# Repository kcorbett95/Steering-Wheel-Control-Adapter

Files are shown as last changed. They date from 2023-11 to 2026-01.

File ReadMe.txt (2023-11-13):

This project is meant to adapt steering wheel media control buttons to aftermarket stereo head-units. It requires the head-unit to use an analog remote
input, usually in the form of a 3.5mm headphone jack in the back of the unit, and the vehicle steering wheel buttons to be a resistor-network type where
each button corresponds to a different resistance value between two wires. Vehicles with many buttons often have 2 input wires and a 3rd reference wire,
where the resistances can be between the reference wire and either input wire, doubling the number of input buttons for the same resistances.

The existing code is currently working on a 2015 Subaru Crosstrek/Impreza and a Pioneer AVH4500NEX head unit. You will need to consult the vehicle
factory service manual to determine what the resistance values for each steering wheel button is, or do some testing with a multimeter to measure each
button manually (this takes forever, don't do this unless you have no other option.) You will also need to know the remote input values the head unit
needs for each function. This information is kindof difficult to find, but I found the values for Pioneer head units after a few hours of digging through
forums and such. An email to the support of your head-unit manufacturer might be helpful in finding this information.

************   MAPPING FUNCITONS    **************
Once you have the required resistance values for both your vehicle, and the corresponding head unit values, the mapping procedure is fairly easy:

1) In the beginning of the SWC_adapter.ino arduino file, you will find the definitions for the head unit values. You will need to replace these values
with the ones for your head unit. 

For example, if your volume up function needs a 55kOhm input, replace the value: 

#define volUp 55000

Repeat this process for the rest of the defined functions. If your vehicle does not have a button corresponding to one of these values, you can either
replace the value with "noBtn" without the quotes if you do not wish to use this function, or you can make a custom value for a button-hold to implement
a different function in later steps (more advanced).

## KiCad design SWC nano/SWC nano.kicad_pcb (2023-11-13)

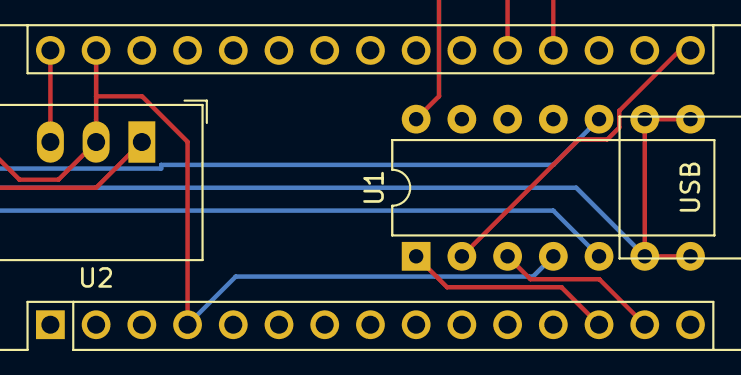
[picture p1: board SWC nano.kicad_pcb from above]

Board: 2 copper layers, 3 parts (0 on the bottom side), 6 nets.

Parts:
A1: Arduino_Nano_v3.x; Arduino_Nano
U1: MCP4251-xxxx-P; DIP-14_W7.62mm
U2: R-785.0-0.5; Converter_DCDC_RECOM_R-78E-0.5_THT

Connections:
/Remote_Ref: U1.6 (P1W), U1.7 (P1A), U1.8 (P0A), U1.9 (P0W)
/SW_Pos_2: A1.27 (+5V), A1.30 (VIN), U1.14 (VDD), U2.3 (OUT)
GND: A1.4 (GND), A1.29 (GND), U1.4 (VSS), U2.2 (GND)
unnamed: A1.13 (D10), U1.1 (~CS)
unnamed: A1.14 (D11), U1.3 (SDI)
unnamed: A1.16 (D13), U1.2 (SCK)

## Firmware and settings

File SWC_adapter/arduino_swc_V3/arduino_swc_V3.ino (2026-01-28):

#include <AceButton.h>
using namespace ace_button;

// Set the SWC input PINs
static const uint8_t BUTTON_PIN1 = A0;
static const uint8_t BUTTON_PIN2 = A1;

// NEC output pin that drives the transistor base
static const uint8_t NEC_PIN = 13;

// Kenwood NEC parameters
static const uint8_t NEC_ADDRESS = 0xB9;
static const uint16_t NEC_BASE = 562;         // us
static const uint16_t NEC_HDR_MARK = 9000;    // 16 * 562.5
static const uint16_t NEC_HDR_SPACE = 4500;   // 8 * 562.5
static const uint16_t NEC_BIT_MARK = 562;
static const uint16_t NEC_ONE_SPACE = 1687;   // 3 * 562.5
static const uint16_t NEC_ZERO_SPACE = 562;
static const uint16_t NEC_RPT_SPACE = 2250;   // 4 * 562.5
static const uint16_t NEC_REPEAT_INTERVAL_MS = 95;

// Event bookkeeping for NEC repeat frames
static uint8_t lastCommand = 0xFF;
static bool repeatActive = false;
static uint32_t lastRepeatMillis = 0;

// Create AceButton objects, with their virtual pin number.
// Each virtual PIN relates to a resistance value on the ladder
static const uint8_t NUM_BUTTONS_1 = 6;
static AceButton volUp((uint8_t)0);
static AceButton volDn(1);
static AceButton trackUp(2);
static AceButton trackDn(3);
static AceButton listInfo(4);
static AceButton back(5);
//static AceButton open1(11);
static AceButton* const BUTTONS_1[NUM_BUTTONS_1] = {
  &volUp,     // 0
  &volDn,     // 48
  &trackUp,   // 111
  &trackDn,   // 197
  &listInfo,  // 319
  &back,      // 530
  //&open1,     // 1023
};

// Virtual pins 6-10 map low->high thresholds: onHook, offHook, source, voice, mute
static const uint8_t NUM_BUTTONS_2 = 5;
static AceButton muteEnter((uint8_t)0);
static AceButton voice(1);
static AceButton source(2);
static AceButton offHook(3);
static AceButton onHook(4);
//static AceButton open2(12);
static AceButton* const BUTTONS_2[NUM_BUTTONS_2] = {
  &muteEnter, // 0
  &voice,     // 47
  &source,    // 108
  &offHook,   // 195
  &onHook,    // 317
  //&open2,     // 1023
};

// Map virtual button index -> Kenwood NEC command (LSB first). Update as needed.
// Unused entries should be 0xFF.
//0xFC,   //AM tuner
//0x83,   //power off

static const uint8_t NEC_COMMANDS_1[NUM_BUTTONS_1] = {
  0x14,  // vol+
  0x15,  // vol-
  0x0B,  // track +
  0x0A,  // track -
  0x8A,  // list/info -> phone menu
  0x0E,  // back (play/pause)
};

static const uint8_t NEC_COMMANDS_2[NUM_BUTTONS_2] = {
  0x16,  // mute/enter
  0x8B,  // voice
  0x13,  // source
  0x88,  // off-hook
  0x89,  // on-hook
};
static const uint8_t NEC_CMD_PLAY_PAUSE = 0x0E;

//
// Define the ADC voltage levels for input pin 1 buttons (ascending, one per button),
// plus the open (no-button) level as the last entry.
static const uint8_t NUM_LEVELS_1 = NUM_BUTTONS_1 + 1;
static const uint16_t LEVELS_1[NUM_LEVELS_1] = {
  0     /* VOL+ */,
  47   /* VOL- */,
  111   /* Track + */,
  196   /* Track - */,
  319   /* List/Info */,
  529  /* Return/back */,
  1023  /* Open */,
};

// Define the ADC voltage levels for input pin 2 buttons (ascending, one per button),
// plus the open (no-button) level as the last entry.
static const uint8_t NUM_LEVELS_2 = NUM_BUTTONS_2 + 1;
static const uint16_t LEVELS_2[NUM_LEVELS_2] = {
  0     /* Mute/Enter */,
  48   /* Voice */,
  111   /* SOURCE */,
  195   /* Off-Hook */,
  319  /* On-Hook */,
  1023  /* Open */,
};

// The LadderButtonConfig constructor binds the AceButton to the
// LadderButtonConfig.
static LadderButtonConfig buttonConfig(
  BUTTON_PIN1, NUM_LEVELS_1, LEVELS_1, NUM_BUTTONS_1, BUTTONS_1, 1);

static LadderButtonConfig buttonConfig_2(
  BUTTON_PIN2, NUM_LEVELS_2, LEVELS_2, NUM_BUTTONS_2, BUTTONS_2, 1);

void handleEventA0(AceButton*, uint8_t, uint8_t);
void handleEventA1(AceButton*, uint8_t, uint8_t);
void handleEventWithMap(AceButton*, uint8_t, const uint8_t*, uint8_t, const __FlashStringHelper*, bool);
void sendKenwood(uint8_t cmd);
void sendKenwoodRepeat();
void handleSerialCommand();
void necMark(uint16_t usec);
void necSpace(uint16_t usec);
void necSendByte(uint8_t data);
void necSendFrame(uint8_t addr, uint8_t cmd);

void setup() {
  delay(1000);  // some microcontrollers reboot twice
  Serial.begin(115200);
  // Wait briefly for Serial on native-USB boards; don't block forever in vehicle power.
  unsigned long serialStart = millis();
  while (!Serial && (millis() - serialStart < 2000)) {
  }
  Serial.println(F("setup(): begin"));

  // Don't use internal pull-up resistor
  pinMode(BUTTON_PIN1, INPUT);
  pinMode(BUTTON_PIN2, INPUT);

  // NEC output defaults low; transistor pulls line when high.
  pinMode(NEC_PIN, OUTPUT);
  digitalWrite(NEC_PIN, LOW);

  // Configure the ButtonConfig with the event handler.
  buttonConfig.setEventHandler(handleEventA0);
  buttonConfig.setFeature(ButtonConfig::kFeatureClick);
  buttonConfig.setFeature(ButtonConfig::kFeatureDoubleClick);
  buttonConfig.setFeature(ButtonConfig::kFeatureLongPress);
  buttonConfig.setFeature(ButtonConfig::kFeatureRepeatPress);
  buttonConfig.setFeature(ButtonConfig::kFeatureSuppressAfterClick);
  buttonConfig.setFeature(ButtonConfig::kFeatureSuppressClickBeforeDoubleClick);
  buttonConfig.setFeature(ButtonConfig::kFeatureSuppressAfterLongPress);

  buttonConfig_2.setEventHandler(handleEventA1);
  buttonConfig_2.setFeature(ButtonConfig::kFeatureClick);
  buttonConfig_2.setFeature(ButtonConfig::kFeatureDoubleClick);
  buttonConfig_2.setFeature(ButtonConfig::kFeatureLongPress);
  buttonConfig_2.setFeature(ButtonConfig::kFeatureRepeatPress);
  buttonConfig_2.setFeature(ButtonConfig::kFeatureSuppressAfterClick);
  buttonConfig_2.setFeature(ButtonConfig::kFeatureSuppressClickBeforeDoubleClick);
  buttonConfig_2.setFeature(ButtonConfig::kFeatureSuppressAfterLongPress);

  
  
  Serial.println(F("setup(): ready"));
}

void loop() {
  // Should be called every 4-5ms or faster, for the default debouncing time
  // of ~20ms.
  buttonConfig.setDebounceDelay(80);
  buttonConfig_2.setDebounceDelay(80);
  buttonConfig.checkButtons();
  buttonConfig_2.checkButtons();
  if (repeatActive && lastCommand != 0xFF) {
    uint32_t now = millis();
    if (now - lastRepeatMillis >= NEC_REPEAT_INTERVAL_MS) {
      sendKenwood(lastCommand);
      lastRepeatMillis = now;
    }
  }
  handleSerialCommand();
}

// The event handler for the button.
void handleEventA0(AceButton* button, uint8_t eventType, uint8_t /* buttonState */) {
  handleEventWithMap(button, eventType, NEC_COMMANDS_1, NUM_BUTTONS_1, F("A0"), true);
}

void handleEventA1(AceButton* button, uint8_t eventType, uint8_t /* buttonState */) {
  handleEventWithMap(button, eventType, NEC_COMMANDS_2, NUM_BUTTONS_2, F("A1"), false);
}

void handleEventWithMap(
    AceButton* button,
    uint8_t eventType,
    const uint8_t* commands,
    uint8_t numButtons,
  const __FlashStringHelper* label,
  bool allowRepeat) {
  uint8_t swButton = button->getPin();
  uint8_t swPress = (eventType);

  if (swButton >= numButtons) {
    return;
  }

  Serial.print(F("handleEvent("));
  Serial.print(label);
  Serial.print(F("): virtualPin: "));
  Serial.print(swButton);
  Serial.print(F("; eventType: "));
  Serial.print(swPress);
  Serial.print(F("; A0: "));
  Serial.print(analogRead(BUTTON_PIN1));
  Serial.print(F("; A1: "));
  Serial.println(analogRead(BUTTON_PIN2));

  uint8_t cmd = commands[swButton];
  if (cmd == 0xFF) {
    return;
  }

  bool isRepeatButton = allowRepeat && (swButton == 0 || swButton == 1);

  switch (swPress) {
    case AceButton::kEventPressed:  // send only on initial press to avoid duplicate click events on release
      lastCommand = cmd;
      repeatActive = false;
      sendKenwood(cmd);
      break;

    case AceButton::kEventLongPressed:
    case AceButton::kEventRepeatPressed:
      if (!allowRepeat && swButton == 0 && swPress == AceButton::kEventLongPressed) {
        lastCommand = NEC_CMD_PLAY_PAUSE;
        repeatActive = false;
        sendKenwood(NEC_CMD_PLAY_PAUSE);
        break;
      }
      if (isRepeatButton) {
        repeatActive = true;
        lastRepeatMillis = 0;
      }
      break;

    case AceButton::kEventReleased:
    case AceButton::kEventLongReleased:
      lastCommand = 0xFF;
      repeatActive = false;
      break;

    default:
      break;
  }
}


void sendKenwood(uint8_t cmd) {
  necSendFrame(NEC_ADDRESS, cmd);
}

void sendKenwoodRepeat() {
  if (lastCommand == 0xFF) {
    return;
  }
  noInterrupts();
  necMark(NEC_HDR_MARK);
  necSpace(NEC_RPT_SPACE);
  necMark(NEC_BIT_MARK);
  interrupts();
}

void handleSerialCommand() {
  if (!Serial.available()) {
    return;
  }

  String line = Serial.readStringUntil('\n');
  line.trim();
  if (line.length() == 0) {
    return;
  }

  char* endptr = nullptr;
  uint8_t cmd = static_cast<uint8_t>(strtoul(line.c_str(), &endptr, 0));
  if (endptr == line.c_str()) {
    Serial.println(F("Invalid command; enter hex or decimal (e.g., 0x14 or 20)"));
    return;
  }

  lastCommand = cmd;
  Serial.print(F("Sending NEC cmd 0x"));
  Serial.println(cmd, HEX);
  sendKenwood(cmd);
}

void necMark(uint16_t usec) {
  digitalWrite(NEC_PIN, HIGH);
  delayMicroseconds(usec);
}

void necSpace(uint16_t usec) {
  digitalWrite(NEC_PIN, LOW);
  delayMicroseconds(usec);
}

void necSendByte(uint8_t data) {
  for (uint8_t i = 0; i < 8; i++) {
    necMark(NEC_BIT_MARK);
    if (data & 0x01) {
      necSpace(NEC_ONE_SPACE);
    } else {
      necSpace(NEC_ZERO_SPACE);
    }
    data >>= 1;
  }
}

void necSendFrame(uint8_t addr, uint8_t cmd) {
  uint8_t naddr = ~addr;
  uint8_t ncmd = ~cmd;

  noInterrupts();
  necMark(NEC_HDR_MARK);
  necSpace(NEC_HDR_SPACE);
  necSendByte(addr);
  necSendByte(naddr);
  necSendByte(cmd);
  necSendByte(ncmd);
  necMark(NEC_BIT_MARK);
  interrupts();
}

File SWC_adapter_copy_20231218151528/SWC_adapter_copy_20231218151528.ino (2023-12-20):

#include <SPI.h>
#define DATAOUT 11//COPI
#define DATAIN  12//CIPO
#define SPICLOCK  13//sck
#define CHIPSELECT 10//cs

//potentiometer selection values, do not alter
#define tip 0b00010001
#define ring 0b00010010
#define Both 0b00010011

//Definitions for output resistances required for stereo, these will need to be changed based on your head-unit and the
//resistance it requires for each media function. See ReadMe for more information
#define noBtn 100000
#define volUp 16000
#define volDn 24000
#define trackUp 8000
#define trackDn 11250
#define listInfo 5750
#define back 62750
#define muteEnter 3500
#define source 1600
#define voice 80000
#define offHook 5000
#define onHook 1500
#define short 0

// initialization code, do not alter
void setup() {
  Serial.begin(9600);
  pinMode(DATAOUT, OUTPUT);
  pinMode(DATAIN, INPUT);
  pinMode(SPICLOCK,OUTPUT);
  pinMode(CHIPSELECT,OUTPUT);
  digitalWrite(CHIPSELECT,HIGH);
  SPI.begin();
  delay(100);
  potWrite(noBtn,Both);
}

//analog read to calculate resistance from vehicle button input, do not alter
double readRes(double analogPin) {
  
  double raw = 0;
  float vout = 0;
  float buffer = 0;
  double res = 0;
  delay(150);
  raw = analogRead(analogPin);
  if (raw>7) {
    buffer = raw * 5;
    vout = buffer / 1024;
    buffer = (5 / vout) - 1;
    res = 1000 * buffer;
    if(res <= 0){
      return noBtn;
    }
    // for debugging, uncomment to view input values in console
    // Serial.print("raw: ");
    // Serial.println(raw);
    // Serial.print("vout: ");
    // Serial.println(vout);
    // Serial.print("Res: ");
    // Serial.println(res);
    delay(50);
    return res;
  }
  else {
    return noBtn;
  }
}

//main function, see ReadMe for information on how to set input ranges and tip/ring output
void loop() {
  
    // Read the values of the two input wires from the steering wheel buttons
    double input1 = readRes(A0);
    double input2 = readRes(A1);

    // Map the values to the corresponding functions
    if (input1 < 25) {
      // Volume Up
      Serial.print("vol up\n");
      potWrite(volUp, tip);
      //delay(5000);
      while(readRes(A0) < 25){
        potWrite(volUp, tip);
        Serial.print("vol up hold\n");
      }
      potWrite(noBtn, tip);
      //delay(5000);
    }

    if (input1 >= 25 && input1 < 75) {
      // Volume Down
      Serial.print("vol dn\n");
      potWrite(volDn, tip);
      //delay(5000);
      while(readRes(A0) >= 25 && readRes(A0) < 75){
        Serial.print("vol dn hold\n");
        potWrite(volDn, tip);
      }
      potWrite(noBtn, tip);
    }

    if (input1 >= 75 && input1 < 175) {
      // Track +
      Serial.print("track up\n");
      potWrite(trackUp, tip);
      while(readRes(A0) >= 75 && readRes(A0) < 175){
        potWrite(trackUp, tip);
        Serial.print("track up hold\n");
      }
      //delay(5000);
      potWrite(noBtn, tip);
    }

    if (input1 >= 175 && input1 < 300) {
      // Track -
      Serial.print("track dn\n");
      potWrite(trackDn, tip);
      while(readRes(A0) >= 175 && readRes(A0) < 300){
        potWrite(trackDn, tip);
        Serial.print("track dn hold\n");
      }
      //delay(5000);
      potWrite(noBtn, tip);
    }

    if (input1 >= 300 && input1 < 575) {
      // List / Song info
      Serial.print("list/info\n");
      potWrite(listInfo, tip);
      while(readRes(A0) >= 300 && readRes(A0) < 575){
        potWrite(listInfo, tip);
        Serial.print("list info hold\n");
      }
      //delay(5000);
      potWrite(noBtn, tip);
    }

    if (input1 >= 575 && input1 < 1200) {
      // Back / Return
      Serial.print("return\n");
      potWrite(back, tip);
      while(readRes(A0) >= 575 && readRes(A0) < 1200){
        potWrite(back, tip);
        Serial.print("return hold\n");
      }
      //delay(5000);
      potWrite(noBtn, tip);
    }

    if (input2 < 25) {
      // Mute/Enter
      Serial.print("mute/enter\n");
      potWrite(muteEnter, tip);
      while(readRes(A1) < 25){
        potWrite(muteEnter, tip);
        Serial.print("mute enter hold\n");
      }
      //delay(5000);
      potWrite(noBtn, tip);
    }

    if (input2 >= 75 && input2 < 175) {
      // Source
      Serial.print("src\n");
      potWrite(source, tip);
      while(readRes(A1) >= 75 && readRes(A1) < 175){
        potWrite(source, tip);
        Serial.print("source hold\n");
      }
      //delay(5000);
      potWrite(noBtn, tip);
    }

    if (input2 >= 25 && input2 < 75) {
      // Voice Control
      Serial.print("voice\n");
      potWrite(short, ring);
      potWrite(voice, tip);
      //delay(2000);  //delay required for some head units to register voice input
      while(readRes(A1) >= 25 && readRes(A1) < 75){
        potWrite(voice, ring);
        Serial.print("voice hold\n");
      }
      potWrite(noBtn, ring);
      potWrite(noBtn, tip);
    }

    if (input2 >= 300 && input2 < 575) {
      // Off-Hook
      Serial.print("off hook\n");
      potWrite(short, ring);
      potWrite(offHook, tip);
      while(readRes(A1) >= 300 && readRes(A1) < 575){
        potWrite(offHook, ring);
        Serial.print("offHook hold\n");
      }
      //delay(5000);
      potWrite(noBtn, tip);
      potWrite(noBtn, ring);
    }

    if (input2 >= 175 && input2 < 300) {
      // On-Hook
      Serial.print("on hook\n");
      potWrite(short, ring);
      potWrite(onHook, tip);
      while(readRes(A1) >= 175 && readRes(A1) < 300){
        potWrite(onHook, ring);
        Serial.print("onHook hold\n");
      }
      //delay(5000);
      potWrite(noBtn, tip);
      potWrite(noBtn, ring);
    }
  }

//write function to set potentiometer output, do not alter
void potWrite(double res, int potNum) {
    //debugging
    //Serial.print("potres: ");
    //Serial.println(res);
    double resDec = (((res-52)*256)/noBtn);
    
    if(resDec >= noBtn){
      resDec = noBtn;
    }else if(resDec < 0){
      resDec = 0;
    }
    //debugging
    //Serial.print("resDec: ");
    //Serial.println(resDec);
    byte resByte = byte(resDec);
    if(resByte == 255){
      Serial.print("reset\n");
    }
    //debugging
    //Serial.print("resByte: ");
    //Serial.println(resByte);
    //byte testData = 0b00011001;
    digitalWrite(CHIPSELECT,LOW);
    SPI.transfer(potNum);
    SPI.transfer(resByte);
    digitalWrite(CHIPSELECT,HIGH);
    delay(50); 
  return;
}
